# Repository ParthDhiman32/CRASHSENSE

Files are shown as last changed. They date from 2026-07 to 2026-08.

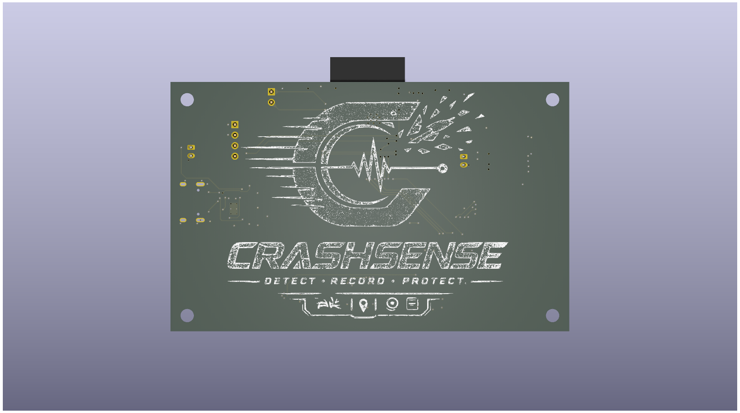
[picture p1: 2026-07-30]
RENDERS/Crashsense PCB Render-2.png

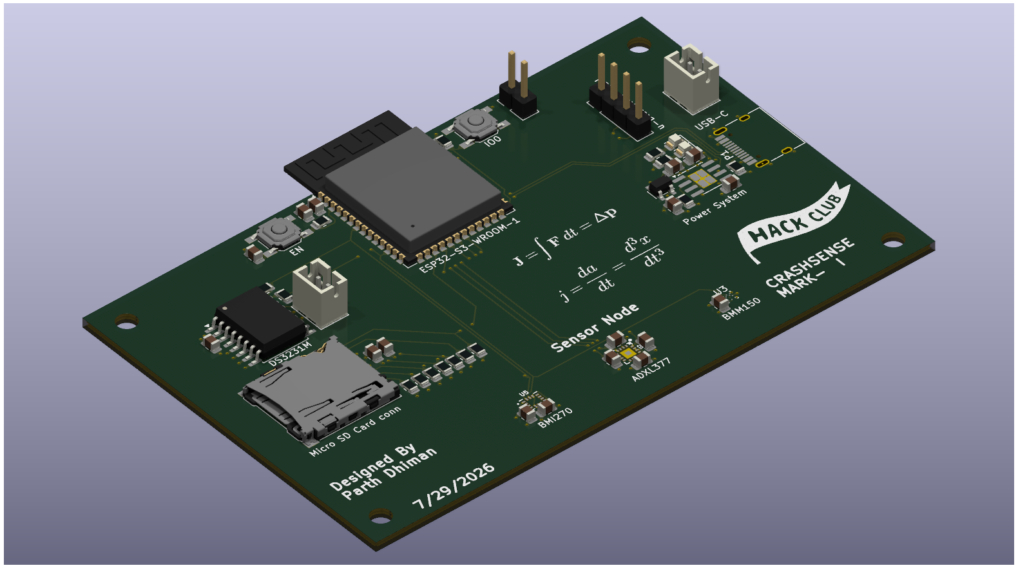
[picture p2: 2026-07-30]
RENDERS/Crashsense PCB Render-3.png

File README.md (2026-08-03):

# CRASHSENSE
Crashsense is a high level embedded sytems project which senses crashes in vehicles like cars trucks and also drones and records crital data of that crash and gives enough data for the crash to be reoncstructed 

# Why did i create this 
i created Crashesense as this is a successor to my older project Dropsense what was dropsense it was simply a embedded system device a PCB inside a hard shell cover which you could drop from any height and it would tell you exactly what height was it droppsed from and also the G-Force with which it impacted the ground

Now this idea grew from a silly project of dropping and analyzing to something bigger i decided to add the best of the best sensors and analyze the data given by then 

Basically Crashsense by it's name you can figure out it is related to something which crashes what crashes?
A lot of things Cars, motorbikes, trucks, drones, ships, and many more vehicles 
Now imagine you could take out something useful from something as negative as a crash from am engineering presepective if Crashsense is intalled in a vehicle from the start if it ever crashes it would give us a lot of DATA....DATA is the most useful thing in engineering which not only tells us how our system behaved but also can be analyzed to fugure out how to make the system behave better and be operate with more accuracy and precision 

Crashsense extracts critical data from a crash like retardation, impact velocity, angle of impact (forward, rear, side, heads on collision) which may be used by engineers to find out how the car crashed and the data may also be analyzed b forensic investigators to collect better evidence. not only all this but if you are making your own custom drone you can install crashsense on it and find out at what exact angle it falls down and how does it fall down and it'll help to pinpoint the point of faliure of the entire system

# HARDWARE & PCB SPECS 

## MICROPROCESSOR
This PCB runs on **ESP32-S3-WROOM-1** operating at speeds of 240Mhz for high frequency data sampling and sensor fusion 

## SENSORS
The main sensors used in this project are 
1. **BMI270** - 6 Axis Inertial Measurement Unit for reading  standard acceleration
2. **ADXL377** - 3 Axis Accelerometer extremely precise readings with massive reading range +-200G
3. **u-blox NEO-M8N** - Additional GPS tracting for pinpointing the location of crash 
4. **DS3231M - precise** timekeeping and timestamping the logged data

## Storage system 
**Push-Push Micro SD-Card Slot** this locks the card firmly inside it's frams and ensures no hinderance with high speed SPI communication 

## Power and Battery Management 
1. **USB-C connector** much better than old micro-usb connectors 
2. **TP4056** for recharing li-ion battries connected in araller for maximum runtime without being connected to external power source
3. **ME6211 3.3V** to step down the 5V input power to stable and low noise 3V3 volts 
4. **Li-ion battries** with JST connector for secure connection 

## Control and Diagnostics #
1. Boot and reset buttons 
2. UART debuggin header (incase USB-C fails to work)

# Schematics




# PCB
Crashsense PCB Render-1
Crashsense PCB Render-2
Crashsense PCB Render-3

# 3D CAD DESIGN



Crashsense Mark-1 3D assmebly v1
Crashsense Mark-1 3D assmebly V2

# BOM
| Component | Designator(s) | Qty | LCSC Part # | Manufacturer Part # | Package | Supplier | Total Price (USD) |
|---|---|---|---|---|---|---|---|
| Esp32 S3 | U1 | 1 | C701341 | ESP32-WROOM-32E-N4 | Module | LCSC | $2.50 |
| LowG IMU/GYRO | U2 | 1 | C2828751 | BMI270 | LGA-14 | LCSC | $2.80 |
| High G accelerometer | U3 | 1 | C138128 | ADXL377BCCZ | LFCSP-16 | LCSC | $6.50 |
| Precise RTC | U4 | 1 | C83023 | DS3231MZ+ | SOIC-8 | LCSC | $3.50 |
| 3v3 LDO Regulartor | U5 | 1 | C6186 | AMS1117-3.3 | SOT-223 | LCSC | $0.05 |
| MicroSD Card slot | J1 | 1 | C114227 | MICRO SPI Push-Push | SMD | LCSC | $0.40 |
| GPS Module Header | J2 | 1 | C124375 | Header 1x05 Pin | 2.54mm Pitch | LCSC | $0.05 |
| Power connector | J3 | 1 | C136657 | XT30PW-M | Right_Angle_SMD | LCSC | $0.50 |
| TVS Diode | D1 | 1 | C83307 | SMAJ5.0A | SMA(DO-214AC) | LCSC | $0.08 |
| Schhotkey diode | D2 | 1 | C8598 | SS14 | SMA(DO-214AC) | LCSC | $0.05 |
| I2C Pull up resistors | R1,R2 | 2 | C8598 | 4.7kΩ 1% | 0805 | LCSC | $0.02 |
| ADXL377 Filter Resistors | R3,R4,R5 | 3 | C25804 | 4.7kΩ 1% | 0805 | LCSC | $0.03 |
| ESP32 Boot/EN Pull-ups | R6,R7 | 2 | C17414 | 10kΩ 1% | 0805 | LCSC | $0.02 |
| ADXL377 Filter Capacitors | C1,C2,C3 | 3 | C15849 | 10nF 50V | 0805 | LCSC | $0.06 |
| Bulk Input capacitors | C4,C5 | 2 | C15850 | 10uF 25V | 0805 | LCSC | $0.10 |
| Decoupling Capacitors | C6,C7,C8,C9 | 4 | C14663 | 100nF 50V | 0805 | LCSC | $0.08 |
| RTC Backup Battery Holder | BT1 | 1 | C70377 | CR1220 Holder | SMD | LCSC | $0.15 |
| **Electronics** | Components BOM (LCSC/DigiKey) | 1 Board | $16.89 | $16.89 | MCU, IMUs, RTC, passives, headers |
| **PCB Fabrication** | 2-Layer FR4 PCB (JLCPCB) | 1 Board (of 5) | $2.40 | $2.40 | ~$12.00 total for minimum 5-pc order + economy shipping |
| **Enclosure** | 3D Printed PETG / ABS Filament | ~50g | $1.00 | $1.00 | Based on standard $20/kg spool (tough PETG/ABS) |

### Total Cost Summary

* **Single Unit Build Cost:** **~$20.29 USD**
* **First 5-Board Prototype Run:** **~$98.45 USD** *(1x $20/kg Filament Spool + 5x Component Sets @ $16.89 + 5x PCBs @ $12.00)*

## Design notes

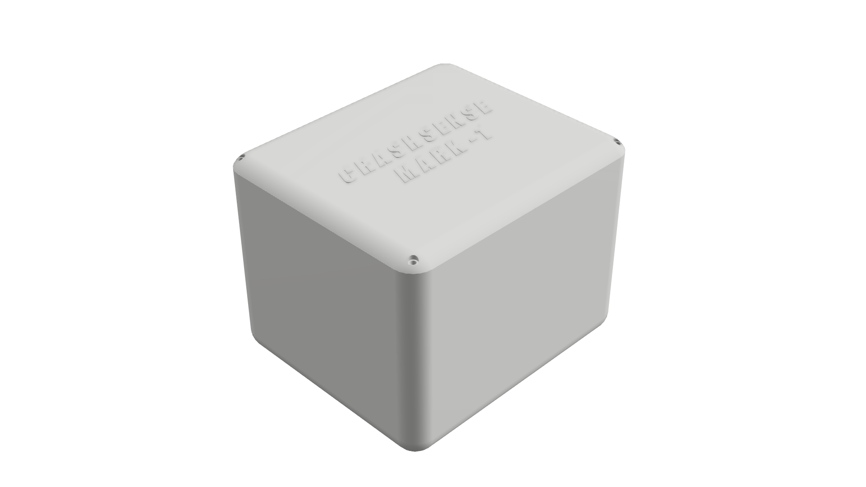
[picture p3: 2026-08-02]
RENDERS/Crashsense Mark-1 3D assmebly v1.png

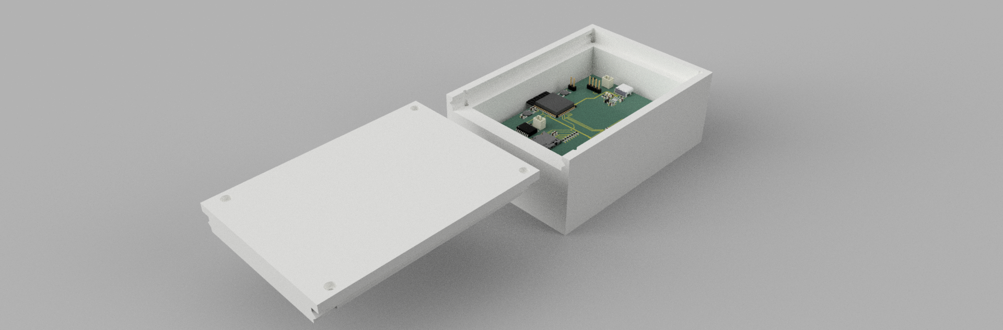
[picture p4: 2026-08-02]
RENDERS/Crashsense Mark-1 3D assmebly V2.png

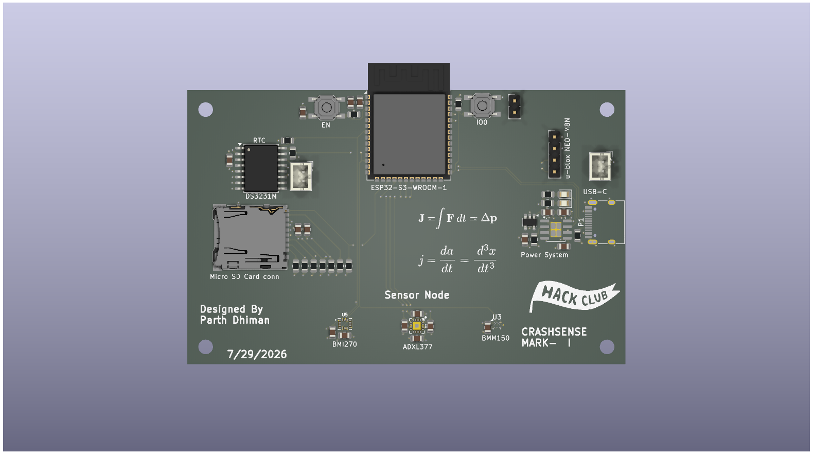
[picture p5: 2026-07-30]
RENDERS/Crashsense PCB Render-1.png

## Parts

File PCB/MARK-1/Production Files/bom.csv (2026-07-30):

Designator | Footprint | Quantity | Value | LCSC Part #
 | f59ac847-f748-4106-ba1d-d1278d51b1ea | 1
C1, C15, C2, C4, C5 | 0805 | 5 | 10uF
C10, C8, C9 | 0805 | 3 | 10nF
C11, C12, C13, C14, C16, C6, C7 | 0805 | 7 | 100nF
C17, C3 | 0805 | 2 | 1uF
D1 | 0805 | 1 | RLED
D2 | 0805 | 1 | GLED
J2 | microSD_HC_Hirose_DM3AT-SF-PEJM5 | 1 | Micro_SD_Card_Det1
J3 | JST_PH_B2B-PH-K_1x02_P2.00mm_Vertical | 1 | BATTERY_CONNECTOR
J4 | PinHeader_1x02_P2.54mm_Vertical | 1 | Debug_pins
J5 | JST_PH_B2B-PH-K_1x02_P2.00mm_Vertical | 1 | Coincell_BAT
P1 | USB_C_Receptacle_HRO_TYPE-C-31-M-12 | 1 | USB_C_Plug_USB2.0
R1 | 0805 | 1 | 5.1KR
R10, R11, R14, R15, R5, R6, R7, R8, R9 | 0805 | 9 | 10KR
R12, R13 | 0805 | 2 | 4.7kR
R2 | 0805 | 1 | 1.2KR
R3, R4 | 0805 | 2 | 1kR
RTC | SOIC-16W_7.5x10.3mm_P1.27mm | 1 | DS3231M
SW1, SW2 | SW_SPST_SKQG_WithStem | 2 | SW_Push
U-BLOX NEO-M8N | PinHeader_1x04_P2.54mm_Vertical | 1 | u-blox NEO-M8N
U1 | ESP32-S3-WROOM-1 | 1 | ESP32-S3-WROOM-1
U2 | LFCSP-16-3X3 | 1 | ADXL377
U3 | WLCSP-12_1.56x1.56mm_P0.4mm | 1 | BMM150
U5 | XDCR_BMI270 | 1 | BMI270
U6 | SOIC-8-1EP_3.9x4.9mm_P1.27mm_EP2.41x3.3mm_ThermalVias | 1 | TP4056-42-ESOP8
U7 | SOT-23-5 | 1 | ME6211C10M5

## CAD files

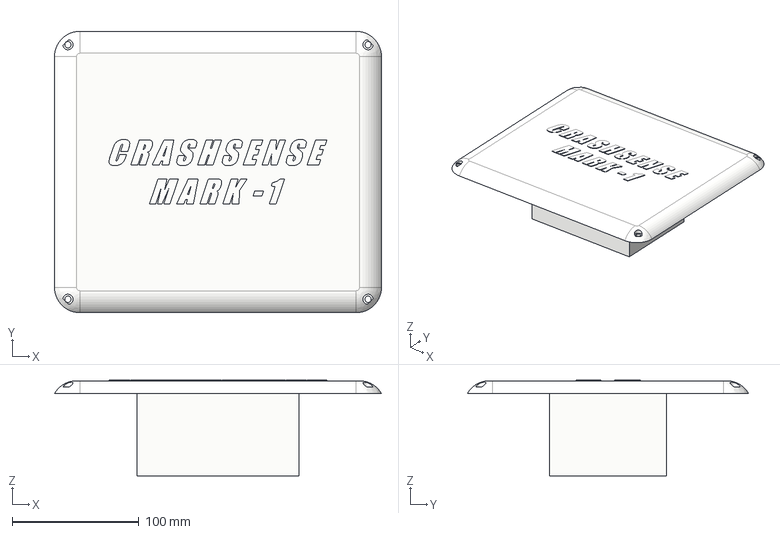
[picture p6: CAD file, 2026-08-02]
CAD/3D Printables/.STEP/Crahsense outter shel part-2 v4.step
258.0 x 222.1 x 75.5 mm

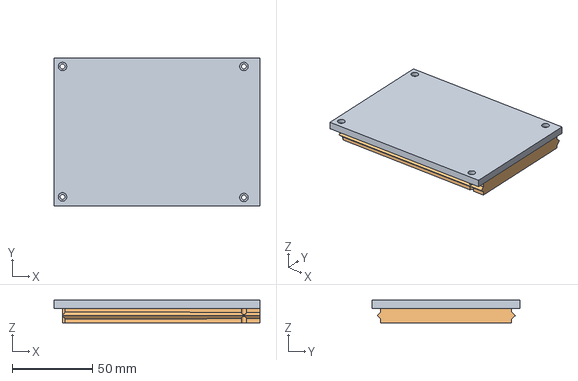
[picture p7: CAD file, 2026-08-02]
CAD/3D Printables/.STEP/Crashsense Mark-1 LID v10.step
128.0 x 92.0 x 14.0 mm

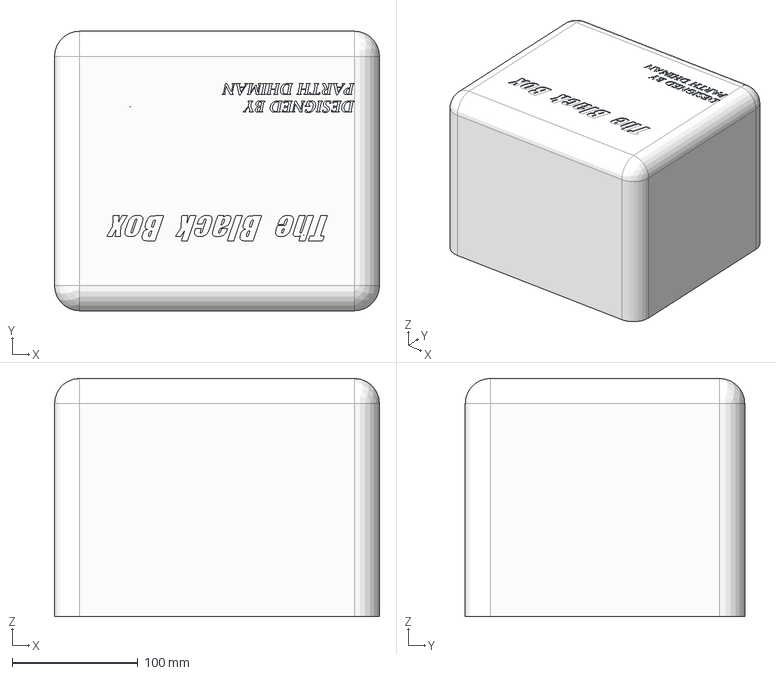
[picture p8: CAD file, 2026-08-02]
CAD/3D Printables/.STEP/Crashsense outter shell part -1 v5.step
258.0 x 222.1 x 189.0 mm

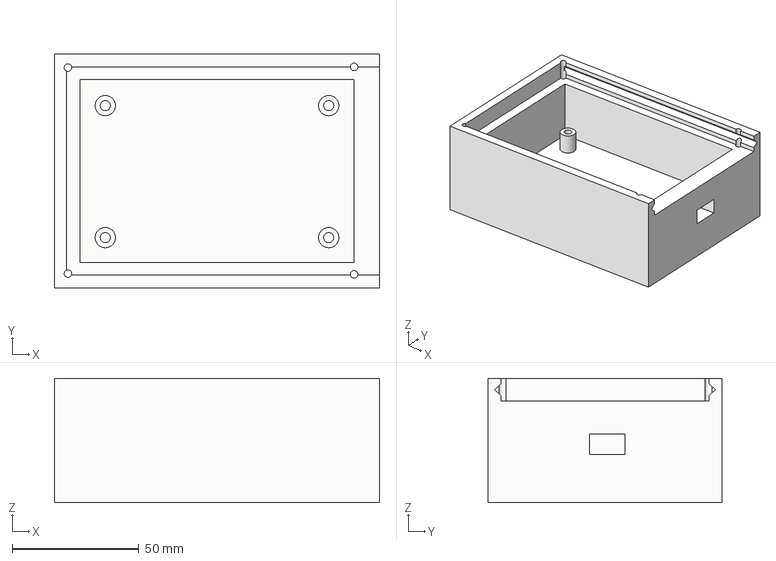
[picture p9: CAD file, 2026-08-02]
CAD/3D Printables/.STEP/Crashsense Mark-1 Enclosure Part-1 v24.step
128.0 x 92.0 x 49.0 mm

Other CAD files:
CAD/3D Printables/.F3D/Crahsense outter shel part-2 v4.f3d
CAD/3D Printables/.F3D/Crashsense Mark-1 Enclosure Part-1 v24.f3d
CAD/3D Printables/.F3D/Crashsense Mark-1 LID v10.f3d
CAD/3D Printables/.F3D/Crashsense outter shell part -1 v5.f3d

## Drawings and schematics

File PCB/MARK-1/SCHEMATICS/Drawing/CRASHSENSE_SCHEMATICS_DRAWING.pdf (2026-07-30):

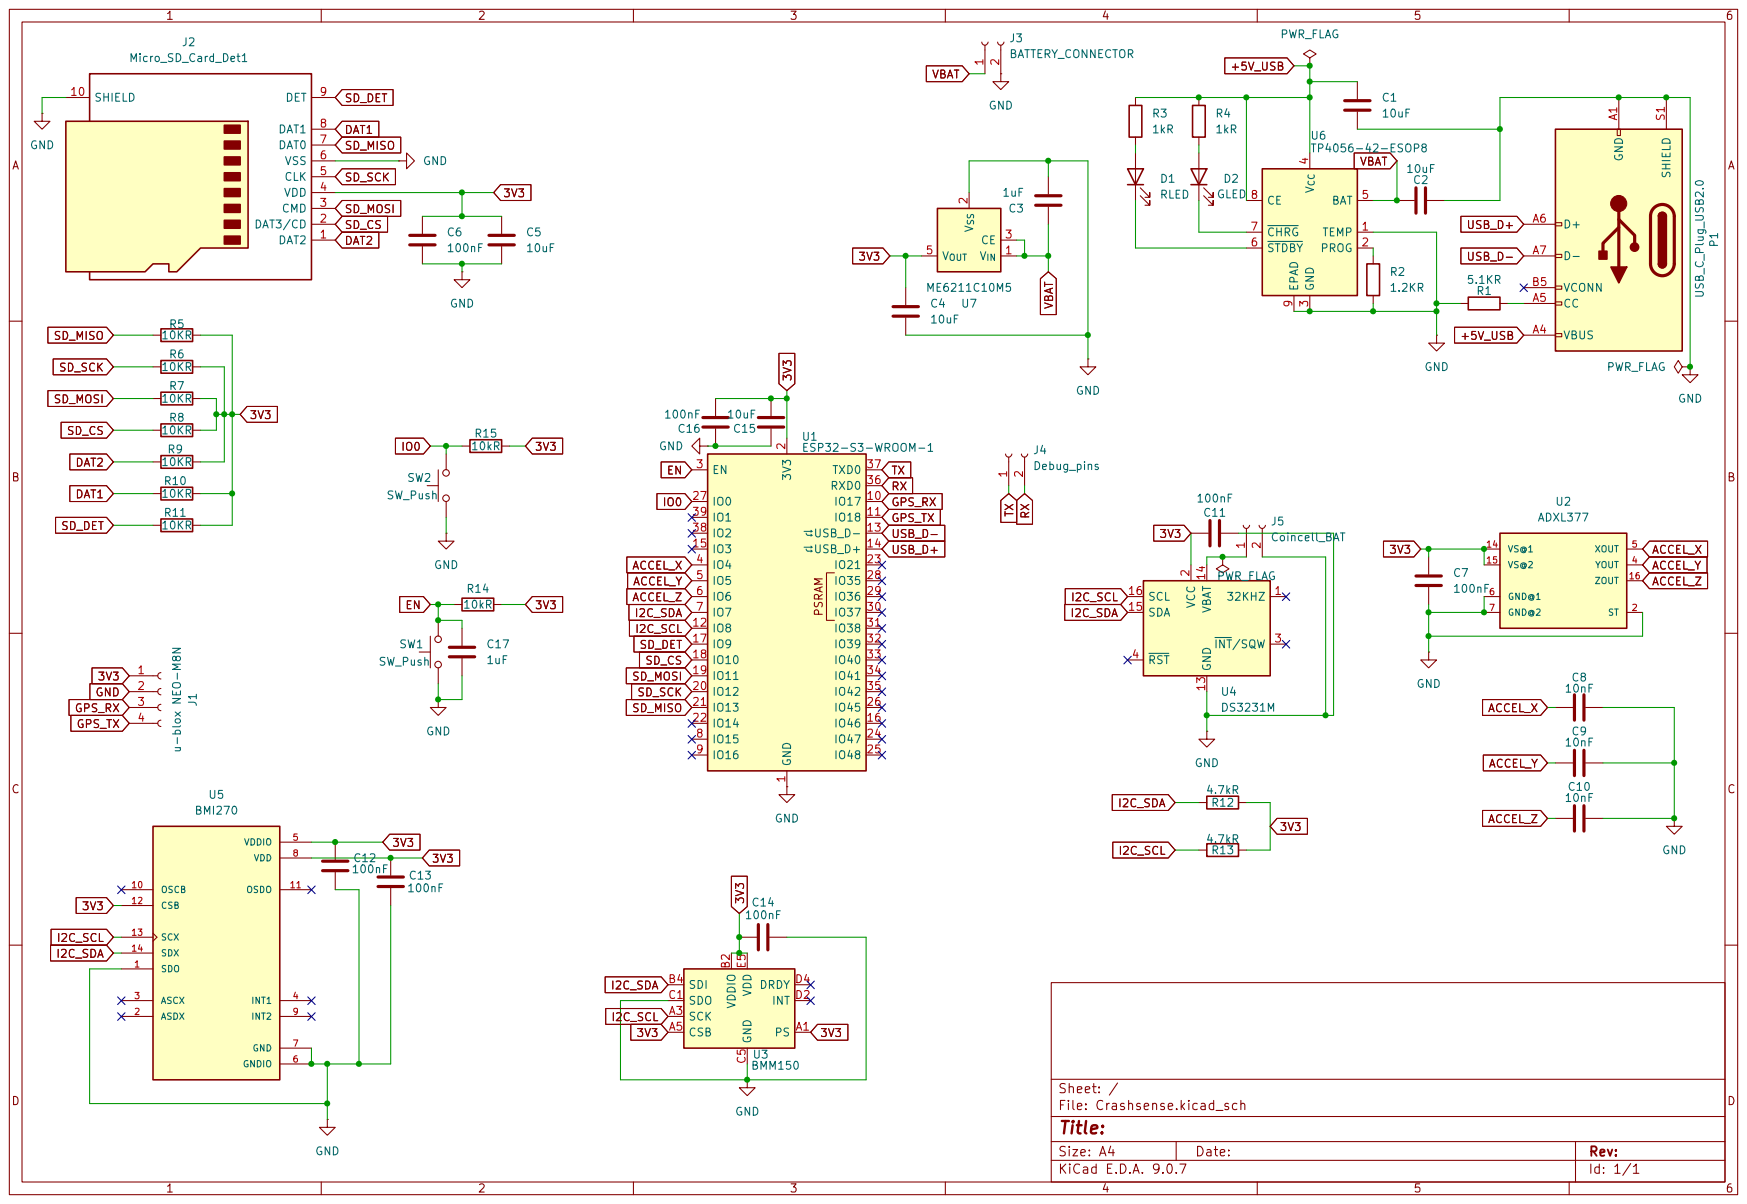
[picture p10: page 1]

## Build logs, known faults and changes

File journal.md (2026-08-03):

---
Title: "Crashsense"
Author: "Parth Dhiman"
Description: "Crashsense is a smart crash analysis system which recods data of a crash and has SOS features"
Created_at: "2026-7-22"
---

# July 22nd: Setting up and researching!

So today is the day i started my work for horizons-equinox in this session all what i did was to simply set up hackatime for VS code and also learn how to journal and use github it was a bit hard to set up because horizons equinox is mainly for software projects but to also log hardware projects i also needed to learn how to sync hackatime and lapse so i can track both my coding time and the time i will be speding on my CAD and PCBs 
So what project am i making is something you might be wondering i am start to work on crashsense actually this is a continuation of my last project Dropsense dropsense was a great learning project basically you could drop it from a certain height and it would log all the data of the drop but now i want to upgrade my project i am going to another level with this project i am willing to make a device which could be mounted in a car ans which could record all sorts of inertial measurements of the car now you would ask me does that not already exist which i would give am answer to as yes! it already does exist but what the point is for making this project is that i am making this project as a learning project and i will also try to include as any features in it as i can so i may also be able to patient it in the future! and yes i will now start to research for this project deciding which are the best sensors to use in this and ones with the maximum data collection rate!

OKay so this is after i researched for the project and i have a lot to say first of all let me list all the parts i will be using in this project 
1. ESP32-S3-WROOM-1
2. ADXL377
3. QMC5883L
4. BMI270
5. micro sd
6. DS3231 
7. u-blox NEO-M8N
8. USB C
9. TP4056
10. ME6211 3v3
so let me talk about each and evey part one by one 

no-1 we have esp32 s3 wroom-1 module which is the microcontroller i will be using for this project this is the brain of the entire system i am planning to use this because of it's very high operational frequency of upto 240Mhz which is enough for my project which needed data sampaling at a very fast rate and also because of it's abundant GPIO pins which will allow me to connect all of the above listed compoennts 
next up 

no-2 ADX377 this is the best accelerometer i could find because it records acceleration upto +- 200g in all 3 axes with maximum accuracy and i don't think a better accelerometer than this for my budget exists i will be using as car crashes have an massive magnitudes of retardation 100-200g and as the range of this sensor falls withing the range of a typicall car crash it will most probably be able to record most of the critical data 

no-3 QMC5883L is a 3 axis digital compass which measure's the earth's magnetic fields accurately and gives accurate compass directions this will help me to figure out what direction the vehicle is heading to The best part i can combine this with the accelerometer and tell if a collision happens which direction did the collision hapenned from read end or frontend or side impact very accurately 

no-4 BMI270 now this is a very powerful gyroscope it also does feature a accelerometer but we do not require that as we are already using ADX377 which is much much better than the accelerometer featured by this 
Now if i combine the acclerometer the compass and this gyroscope sensor together i now have the ability to capture a new variety of crash which is if the car rolls over or falls down a hill now i can detect rotation yaw and pitch by sensor fusion 

no-5 i will be using a simple sd card module to log the data now you may be asking why use a sd card they are not that fast to log tens of thousands of bits of data at a very low frequency now we can fix this issue by simply logging a chunk of data in the 512KB of Sram the esp32 s3 wroom-1 offers and then load that into the sd card at once ad repeate this process and it makes logging the data much more relaible 

mo-6 DS3231 is a RTC module which i will use to add timestamps to each of my readings in formats of dd/mm/yy for header reading and then readings for the actual logged data will be logged in intervals f miliseconds as per the esp32 s3 wroom-1' clock

no-7 u-blox NEO-M8N this is a pretty good enough GPS for crashsense as i also want to record the velocity of the crash and also for future upgrades i want to give the exact co-ordinates where the crash most probably took place 

no-8,9,10 TP4056 now here comes the power system which i would like to cover all together so first up comes the usb-c which i will using to power program and test the entire pcb firstly the 5V power enters through the USB and then i use the TP4056 module to charge the onboard li-ion battery which will power the entire system for now i will add a more complex power system in the pcb which enable the pcb to run directly off of the 11.8 to ~14 V from the lead acid car battery and yes i will also add supercapacitors later incase the battery wires snap during a crash 



**Total time spent: ~2h** for the lapse + journal if talking only about the journal i spent a exact time of 1 hour and 7 mins on it because i mostly did research and wrote my views here today 

# July 23rd: Deeper research and Pcb schematic development!

So guys today's decided goal is to complete adding all the parts i need for my project in the schematic and then 
hopefully start the routing 

So i decided to make a change in the magnotemeter i'll be using instead of using a QMC5883L 3 axis magnometer 
i will instead use BMM150 which is also a 3 axis magnetometer but this one is made by bosch and hence 
is much more relaible

so first of all what i did was to place all the parts in the KiCAD schematics editor 
I got most of the parts in the default library but i needed to add a few special sensors like ADXL377 and the 
BMI270 3 axis accelerometer and gyroscope from bosch 

now first of all i started to wire up the power system consistong of a USB C connector TP4056 for charging the battery and also a ME6211 to step down the voltage from 5V from the USB C to 3V3 volts on which the entire system will operate on if any sensor requires exact 5V signal i will either use a I2C signal logic level converter because f i directly feed the sensor 5V it will be output 3V3 signals to my ESP32 S3 and cook it 

so i worked on the power system i wired up a USB C connector to my TP4056 battery power managemnent IC and use it to charge my 
li-ion battries and also give the 3V3 volt regulator aka the ME6211 which is being fed the 5V from the TP4056 
for it to be convertyed into stable 3V3 volts also i added 10uF capacitors at the input and output of each of the 
regualtors to store power and to stabelize voltage fluctuations which may take place 


after this i wired up the sd card module and added net labels for easily connecting them to my ESP32 S3 WROOM-1 module 
also i added one 10uF capacitor at the inputs of the SD card module to stabelize the voltage and a 100nF capacitor to 
filter out the any noise in the power signals which may interfere with the SD card module 


## overall PCb schematic as of today 


**Total time spent: ~2.5h** (including lapse and journalling)

# July 24th: PCb schematics continued!

sooo guys my goal for tonight is to route 3 more sensors properly like not properly perfectly flawlessly so that 
i would not worry about my connections being wrong 

I started by wiring up the very easy u-blox-NEO-M8N GPS which uses only vcc gnd and I2C pins which make 
the connections very easy 

then i connected the ADX377 to my esp32 s3 i added a 100nF decoupling capacitor and also added 10nF capacotors at X Y and Z 
output pins to set the data sampaling speed to 200Hz

after that i made a master I2C rail over which i connected all the I2C devices mainly the DS3231M RTC 

and lastly i connected the BMI270 IMU which i'll be using for reading the gyroscopic values for all 3 axes 


\



**Total time spent: ~1.3h** (including lapse and journalling)

# July 25th: PCB schematics finished!
So guys my goal for today is to finish the pcb and then organize the schematics and optimize it for redability 
to make it look proffesional afterall

so firstly i wired up the last piece the BMM150 the 3 axis compass which will be used for telling which direction the vehicle 
is headed to and from where did the crash occur 

what i learnt that i always have to connect a 100nF resistor with every IC because it stabelizes the power input 
and also helps to reduce impact of high frequency signals on the IC 

as for the ESP32 S3 wroom-1 module which i mostly use in my projects i need to connect 2 resistors to it 
firstly the bulk charge holder 10uF capacitor and then the noise reducing capacitor aka the 100nF capacitor 
the combination of the two helps with fluctuating power and signal noise 

alright now after adding these changes i also added the RC delay circuit for the EN pin with a 10kR resistor 
and a 1uF resistor and a reset circuit for the IO0 pin to decide wether to put the ESP32 in running or uploading module

then i also added 2 pins the RX and TX as pin headers on the PCB so that i can still upload the code to my esp32 
is my USB fails to program or detect the ESP32 which has hapenned to me in the past so i mostly use a FTDI 
module connected to the ESP32's RX and TX pins to flash it 

now i have another bigger obstacle in my way i need to organize everything all the components in the schematic

alright now i organised everything inside the schematic
The power delivery system is at the top right 
The esp32 s3 wroom-1 with all it's connection flags is placed in the center the accelerometer and the gyroscope sensor to it's right
The RTC and the RC delay and Reset circuits are on the leftthe sd card module on the top left 

Now i ran the most critical part the ERC 
first it showed 5 errors and 3 warnings 
the 5 errors pominted to 2 unconnected pins which i forgot to place a no connection mark on and 
the other 3 were pointing at the +5V_BAT the 3V3 and the GND i just needed to add 3 PWR_FLAGS to them to fix it
Then i ignored the warnings because they were pointing at some silly stuff and i saw ZERO!!!!! DRC errors

now i added footprint for each and every component used from a single resistor to the BMI270 all have the footprints assigned
now i converted everything to a pcb and i already know it is going to be a hell of a routing session 

Here are the screenshots of today's work 






Which i decide to save for tomorrow 

**Total time spent: ~2.2h** (including lapse and journalling)

# July 26th: PCB component placement started!

Alright guys so yesterday i had completed the pcb schematics and today i started to arrange all the components on the pcb 

So the strategy i use to arrange the components perfectly is that i divide the entire PCB into sub systems like the power system the micro controller system and each and every sensor is firstly seperated 

I would call this a pretty good feature of Kicad that it lets us select the components on the pcb editor just by selscting them in the Schematics editor this does not exist in easy EDA 

Anyways after diving each and ever subsystem i start to place the passive SMD components like resistors capacitors connectors and inductors close the the main chip that im working on for eg the most crutial part is the power system so to ensure minimum EMI the compoenets need to be as closely packed as possible like the smd components need to be hugging the power IC like actually so close that it literally cannot be any closer this helps to greatly reduce EMI and keeps the signals stable and noise free because long power traces can act as a antenna and disturb other components such as the most sensetive magnetometer 

after the power system i worked on the ESP32 as i said earlier the decoupling capacotors near the ESP32 S3 should should be placed as close it as possible

Then moving on to the SD card module if you look closely you'll be able to see an array or resistors which are connecting to the SD card module and 3V3 rail That is an array of Pull up resistors pulling up each and evey single pin on the SD card module because without it the micro SD card module becaomes highly unstable and may be affected by tiny bt of electro magnetic interference and read data wrongly and may even corrupt the SD card module 

Then we move to the sensors in this PCB the ADXL377 and the BMI270 are placed close to each other because they can be BUT! you may notics that the BMI270 is kept far away from each of these sensors and even the power rails this is done on purpose because the BMI150 is a very accurate but ultra sensetive magnetemeter and even a tiny bit of current will WILL acceft it's reading so that is the reason why this HAS to be kept away from evey other component 

and then in the end what I needed to do is to make a Edge.Cuts layer of size aprox 70 by 50 mm inside which i had to keep att the components now this is pure hit and trial you need to logically reason the placement of every subsystem on the PCB in such a way it compliments the working of other subsystem instead of interfering with then like the ESP32 and the power system are best friends and need to be together for proper power delivery and the RTC module is above the SD card module because the array of the Pull up resistors need space for connecting with the ESP32 and so and so 

Now today's goal is complete and now i plan to route this PCB tomorrow and make minor adjusments in the layout for ease of routing 

Here is how the PCB looks today after today's work VS how it did look yesterday 
**Yesterday**

**Today**


**Total time spent: ~~2h** (including lapse and journalling)

# July 27th: PCB component Routing disaster!
sooo guys i started to route my pcb today and i went for a 4 layered PCB because i had never made it before and i guessed it would be the perfect opputunity to learn 
how to trace a 4 layered PCB 

But things didn't go as planned well they did i routed a lot of things but the thing is that i myself do not understand properly how did the connections trace like 
i cannot see each and every tract properly taht's why it seems very very confusing but yes i can say i did make progress but i am not able to recognize it properly 

anyways i do not have a lot to say today so i would like to imclude a screenshot of today's work and end it also because i haven't slept properly so i should sleep 


**Total time spent: ~1h** (including lapse and journalling)

# July 28th: PCB rerouting with peaceful mind  !
SOO GUYZZ so first of all i started by unrouting all the traces i made because they just didn't feel right and i felt like i speedran 
then and after that i reomved all the components out of the edgs.cuts layer and started to place each and every sub-system together 
and i also decided that i will need to increase the size of the pcb because a smaller form factor would only make things really hard 
to route so as the engineering industry standard if something doesn't work i just scrap and discard it and start over again 
that is exactly what i did i discarded the old component placement and then seperated each and every systed and 
adjusted every capacitor or resistor which i felt like needed to be.

after adjusting every single component the next part was that i needed to convert the PCB physically into a 4-layered PCB for that i first needed to go 
in FILE and then BOARD SETUP and then PHYSICAL STACKUP 
then i needed to change the no of layers from 2 to 4 layers and kicad automatically added in1 and in2 layer 
So the in1 layer was configured as the GND plane and the in2 layer was configured as the 3V3 plane 
as the entire board runs on 3v3 volts i only need GND and 3V3 as 2 extra layers for seperating the power system from the rest 
of the board 

Then after doing this i started to route the PCB first of all what i needed to do was to add vias to all the GND 
pads so that i could connect them directly to the GND plate 

after adding all the GND vias i realised that every via must be as close to the pad as possible so i rechecked every via i made and 
then made minor adjustments in the location of vias with respect to the GND pad 

here is the yesterday's before and today's after 

## BEFORE ##


## AFTER ##


If you cannot tell the difference let me explain so first of all the yesterday's PCB is much much smaller and cluttered than the pcb i made today 
and also the new pcb has M3 mounting screws in comparision to the old one which doesn't even have a proper visibally viable division of sub-systems  

Also the most important update that i made in this PCB is that i added a sensor array at the base of the PCB as the snsors share the same horizontal axis on the 2 dimensional plane of the PCB they will be synced and provide harmonius information which is more accurate and can be worked uptom more freely

**Total time spent: ~1.3h** (including lapse and journalling)

# July 29th: PCB final routing and makeing it look good!

Sooo guyss today's session was longer than other session because now i am going to speedrun the PCB now as the deadline is getting close 
So about what i did Today

as of yesterday i was routing the GND pads by that i mean adding VIA for GND near every GND pad and why is that so you may as??
This is because i was making a 4 layered PCB well i was going to give up and make a 2 layered PCB instead but no 
i did continue with the 4 layered one so till yesterday i had added all the GND VIAS and today i contunued by adding the
VIA for the 3V3 plane and then i soon realised i made a blunder which would cost me a lot in manufacturing the PCB 
the blunder i made was that i asses the 3v3 pads as close to the pad as possible ik that is how it is supposed to be but my mistake was that i made the pad and the VIA touch 
which seemsokay in design stage of PCb assembly but causes the manufacturing cost to shoot up because during the solder reflow stage of the PCB the 
solder runs down through the holes and more of it ends up being used and hence costing more 

now after this what i did was to rerout the power system for the power system i started by routing the TP4056 IC and then 
the ME6122 3V3 voltage regulator LDO  and then i used a lot of brain in maximizing the efficiency of the power system by reducing the trace length and using VIA 
efficiently 

After the voltage regulation body i.e. power system was done i moved over to connecting the power pins of the ESP32 
first the power pins and then the EN and IO0 switches were wired up something different that i did this time that i do not usually do while routing pcbs is that 
when i make traces most of the times i just folow what the software guides me as the best track or VIA position but i learnt that if i hold down the CTRL key
and then move my mouse then the track used to move very smoothly as if now i have entire soul of the track in the pal of my hand 
now i made a lot of very beautiful traces that i am really proud of 

Then i worked my way over to the I2C rails i had a very good idea this time that i will first make a common rail 
for every I2C device which was a really good idea because it worked properly and it also looked much better then connecting the I2C 
traces any other way after my inner perfectionist perfected the tracks i was satsfied and then 

and then was left another sesnr or two why? because they had different pins because they use SPi protocol instead of 
I2C protocol like the micro SD Card module and then ADXL377 

and after this i was done with allll the connections 

Then....i ran the DRC and it showed me 8 errors and 15 warnings from those 8 errors 5 errors were that i had left unconnected items in the power system 
but in reality the thing is that i did wire them up but suddenly i pressed shift + W and idk when i press it my computer crashes everytime 
and i have to start Kicad again but it loads it from the place of last save 

Anyways after fixing those 5 errors i went to 3 more errors which were telling me that the edge.cuts layer wasn'ta
aligned properly with the 3V3 and the GND plate then i shifted the border a bit and fixed the PCB now i only had warnings telling me to not clip the silkscreen but bro now i can ofc 
have silkscreen over or under the electronics it's not like it will interfere with the PCB 

After doing any and every change i could have done to beautify the PCb like i even added teardrops in the PCb and after that the 
VIA suddenly looked much much better 

now came the fun part i imported a few SVj files to add on the PCB 
mo-1 i wrote my name and project name "Crashsense mark-1" and also the date i made it and then i added hack club' flag 
to the front of the PCB and an AI generated very cool SVJ file which was a graphical symbol of crashsense on the entire back of the PCB 
and lastly i added the core of the systed i added 2 hysics equations on whose principal does crashsense work and then put them near the heart of the ESP32

Okay so i think these are enough for today now i should sleep properly 

here are the PICs of today's work






**Total time spent: ~3.5h** (including lapse and journalling)

# July 30th: PCB Finalization!
SOOO GUYZZ today what i did was that firstly i rendered the pcb i took one render from the top view of the PCB
another from the back side of the PCB which has the crashsense logo and 3rd render was a sideways slanting render
which looked absoultely fire 

after this i explorted the production files for the PCB like the GERBER the BOM and the PLACE file for the PCB 
using the custon added fabrication toolkit 

then i also exported the schematics of the pcb as a PDF file inside the PCB folder and yeah after this i ploshed 
the readme added different sections and many many images of my work

andd after all of updating the readme writing new things and highlighting all the stuff about the PCb I did till now i started to work on the 3D Enclosure for the PCB and that's when i realised i don't have a very clear idea of how the actual 3d design should look but for the begining i will make a very simple enclosure and then work on it and transform it into an even better design day by day hour by hour minute by minute 

I have the theoretical design in my head that is that this project will have a inner hard PETG shell inside which the pcb will be present and a soft outter TPU shell which will deform and squish during the impacts and let the inner hard shell protect the PCB 
actually during an impact what i really want that survives is not the PCb but rather the Mirco SD card module because it will be storing all of the critical data and furthermore i plan to make the areas where the SD card resides the toughest area 

Here is the design made till now


**Total time spent: ~2h** (including lapse and journalling)

# July 31st and 1st august: 3D Design progress!
Alright so today was a pretty productive day what i did was work on the 3D CAD enclosure for my PCB which 
i had started yesterday on yesterday it was just a single part box 

today i made the following changes 
1. Made a cutout for the USB Type C connector in the enclosure 
2. Added M3 heat inserts in the small pillars i made for mounting the PCB regidly 
3. Added M3 screws to mount the PCB inside the enclosure 
4. Added a lip on the outter perimeter of the TOP of the enclosure for sturdy connection with the LID 
5. started working on the lid and made a coresponding outter lip on it's perimiter for proper locking of the lid
6. Added M3 screws connecting the lid and the enclosure together 
7. added a interlocking lip for sturdy connection of the lid with the body 
8. created outter hexagonal pattern housing which will sqush and break on impact protecting the inner PCB 






**Total time spent: ~5-6h** (including lapse and journalling)

# 2nd August: Outter shell designing and assembly video!
SOOO GUYZZ in today's session i worked on the outter hexagonal design for the PCB this outter shell is intended to crush and break on impact to protect the inner 
Main PCB housing of Crashsense 

The utteroutter housing holds the inner housing and there is a 5mm wall between the inner and outter housing before the haxagonal pattern starts and 
also a 5mm thick outter wall on the perimeter of the outter shell and the inside is filled with hexagons and when it will be hit the outter wall will distribute the impact to a 
specific wall and the entire wal will transfer the force toi a array of hexagons instead of a specifi hexagon and will make the
all the hexagons compress on impact and once the force ends the hexagons will restore to their initial position if the impact was not strong 
enough to break them 

after completing this design i took a few renders of the entire design 

after thr renders i made a exploded view of the entire assembly and also animated each part showing how the assembly works and it should exisit this is the yt video link
https://youtu.be/XTUrnmSj-00
after making the animation and uploading it on youtube 
I started to export all the CAD files in the respective folders and make each and everything organised 

and now the entire CAD and PCB part of this project stands complete i will now proceed to ship this project 

Crashsense Mark-1 3D assmebly v1
Crashsense Mark-1 3D assmebly V2

**Total time spent: ~2h** (including lapse and journalling)

# 2nd and 3rd August Starting and finishing up code!

first of all i replaced the traditional loop() approach because reading sensors and wiring data to the SD card could easily cause delays and miss data 

I designed a dual core memory firmware architecture using FreeRTOS 

1. Core 0 Reads data from the ADXL377, BMI270, and Neo-M8N every 5 ms (200Hz) and stores it in a ring buffer containing 2 seconds of data 

2. Core1 Waits in the background untill a crash is detected and then saves the buffered data along with the 5 seconds of post Crash data to the SD card.

Developed crash detection logic that continuoosuly checks the acceleration and if the acceleration stays above a threeshold for a short period of time the system triggeres data logging 

the firmware now does not interfere with the SD card ogging and reading the Sensor data 

**Total time spent: ~2h** (including lapse and journalling)

# 3rd August Finalizing the BOM!
SOOO GUYS in this video i exported the ropugh BOM from kicad and then formatted a few more things and now i have a rough cost of the project which comes out to be around 16$ and this does not include the fabrication cost because that varies manufacturer by manufacturer and rough cost would be around 10$ 
yk what let me just include it 
 
anyways as this project is already shipped i do not have much to do but wrap up this project

**Total time spent: ~1h** (including lapse and journalling)

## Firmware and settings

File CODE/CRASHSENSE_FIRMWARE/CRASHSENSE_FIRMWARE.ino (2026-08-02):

/** CRASHSENSE MARK-1 FIRMWARE **/
#include <Wire.h>
#include <SparkFun_BMI270_Arduino_Library.h>
#include <RTClib.h>
#include <TinyGPS++.h>
#include <HardwareSerial.h>
#include <SPI.h>
#include <SD.h>

// --- PIN DEFINITIONS & CONSTANTS ---
#define RXD2 16
#define TXD2 17 
#define GPS_BAUD 9600 

const int PIN_X = 32; 
const int PIN_Y = 33;
const int PIN_Z = 34;
const int SD_CS_PIN = 5; // Standard ESP32 VSPI CS pin

const float V_REF = 3.3;            
const float ADC_MAX = 4095.0;       
const float ZERO_G_VOLTS = 1.65;    
const float SENSITIVITY  = 0.0065;  

// --- GLOBAL OBJECTS ---
RTC_DS3231 rtc;
TinyGPSPlus gps;
HardwareSerial gpsSerial(2); 
BMI270 imu;

// --- DATA STRUCTURES & RTOS GLOBALS ---
struct SensorFrame {
  uint32_t timestamp_us;
  float ax, ay, az;
  float gx, gy, gz;
  float lat, lng;
  uint8_t hour, minute, second;
};

const int BUFFER_SIZE = 400;
SensorFrame ringBuffer[BUFFER_SIZE];
volatile int headIndex = 0;

QueueHandle_t crashQueue;
TaskHandle_t SensorTaskHandle;
TaskHandle_t SDTaskHandle;

// --- CORE 0: HIGH SPEED SENSOR TASK ---
void core0_SensorTask(void *pvParameters) {
  TickType_t xLastWakeTime = xTaskGetTickCount();
  const TickType_t xFrequency = pdMS_TO_TICKS(5); // 200 Hz

  int impactCounter = 0;
  bool crashStatusLocked = false;

  for(;;) {
    // 1. Read Analog Accelerometer
    float gX = (((analogRead(PIN_X) / ADC_MAX) * V_REF) - ZERO_G_VOLTS) / SENSITIVITY;
    float gY = (((analogRead(PIN_Y) / ADC_MAX) * V_REF) - ZERO_G_VOLTS) / SENSITIVITY;
    float gZ = (((analogRead(PIN_Z) / ADC_MAX) * V_REF) - ZERO_G_VOLTS) / SENSITIVITY;

    // 2. Read Digital IMU
    imu.getSensorData();

    // 3. Update GPS data in background (non-blocking)
    while (gpsSerial.available() > 0) {
      gps.encode(gpsSerial.read());
    }

    // 4. Get Time
    DateTime now = rtc.now();

    // 5. Write to Ring Buffer
    ringBuffer[headIndex].timestamp_us = micros();
    ringBuffer[headIndex].ax = gX;
    ringBuffer[headIndex].ay = gY;
    ringBuffer[headIndex].az = gZ;
    ringBuffer[headIndex].gx = imu.data.gyroX;
    ringBuffer[headIndex].gy = imu.data.gyroY;
    ringBuffer[headIndex].gz = imu.data.gyroZ;
    
    if (gps.location.isValid()) {
      ringBuffer[headIndex].lat = gps.location.lat();
      ringBuffer[headIndex].lng = gps.location.lng();
    }
    
    ringBuffer[headIndex].hour = now.hour();
    ringBuffer[headIndex].minute = now.minute();
    ringBuffer[headIndex].second = now.second();

    // 6. Crash Detection Logic
    float aTotal = sqrt((gX*gX) + (gY*gY) + (gZ*gZ));
    
    if(aTotal > 5.0 && !crashStatusLocked) {
      impactCounter++;
      if(impactCounter >= 4) {
        crashStatusLocked = true;
        int freezeIndex = headIndex;
        xQueueSend(crashQueue, &freezeIndex, portMAX_DELAY);
      }
    } else {
      impactCounter = 0;
    }
     
    // 7. Advance Buffer and Delay
    headIndex = (headIndex + 1) % BUFFER_SIZE;
    vTaskDelayUntil(&xLastWakeTime, xFrequency);
  }
}

// --- CORE 1: ASYNCHRONOUS SD CARD TASK ---
void core1_SDTask(void *pvParameters) {
  int freezeIndex = 0;

  for(;;) {
    if (xQueueReceive(crashQueue, &freezeIndex, portMAX_DELAY) == pdPASS) {
      File dataFile = SD.open("/crash_log.csv", FILE_APPEND);
      if (!dataFile) {
        vTaskDelete(NULL); // SD failure, kill task
      }

      // Dump pre-crash history
      int readIndex = (freezeIndex + 1) % BUFFER_SIZE;
      for(int i = 0; i < BUFFER_SIZE; i++) {
        dataFile.print(ringBuffer[readIndex].timestamp_us); dataFile.print(",");
        dataFile.print(ringBuffer[readIndex].ax, 2); dataFile.print(",");
        dataFile.print(ringBuffer[readIndex].ay, 2); dataFile.print(",");
        dataFile.println(ringBuffer[readIndex].az, 2);
        // (Add gyro, lat, lng, time prints here to match your CSV headers)
        readIndex = (readIndex + 1) % BUFFER_SIZE;
      }
      
      dataFile.flush();

      // Capture post-crash data
      int postCrashFrames = 1000;
      int lastWrittenIndex = freezeIndex;

      while (postCrashFrames > 0) {
        if (headIndex != lastWrittenIndex) {
          lastWrittenIndex = (lastWrittenIndex + 1) % BUFFER_SIZE;
          dataFile.print(ringBuffer[lastWrittenIndex].timestamp_us); dataFile.print(",");
          dataFile.print(ringBuffer[lastWrittenIndex].ax, 2); dataFile.print(",");
          dataFile.print(ringBuffer[lastWrittenIndex].ay, 2); dataFile.print(",");
          dataFile.println(ringBuffer[lastWrittenIndex].az, 2);
          postCrashFrames--;
        } else {
          vTaskDelay(pdMS_TO_TICKS(1));
        }
      }
      
      dataFile.flush();
      dataFile.close();
      vTaskSuspend(NULL);
    }
  }
}

// --- SYSTEM INITIALIZATION ---
void setup() {
  Serial.begin(115200);
  gpsSerial.begin(GPS_BAUD, SERIAL_8N1, RXD2, TXD2);
  Wire.begin();
  Wire.setClock(400000); 
  analogReadResolution(12);

  // Initialize Sensors
  if (imu.beginI2C(0x68) != BMI2_OK) {
    Serial.println("BMI270 NOT DETECTED");
    while (1);
  }
  if (!rtc.begin()){
    Serial.println("Cannot find RTC");
    while (1);
  }
  if(rtc.lostPower()) {
    rtc.adjust(DateTime(F(__DATE__), F(__TIME__)));
  }
  
  // Initialize SD Card
  if (!SD.begin(SD_CS_PIN)) {
    Serial.println("SD Card Mount Failed");
    while (1);
  }

  // Create IPC Queue
  crashQueue = xQueueCreate(1, sizeof(int));
  if(crashQueue == NULL){
    Serial.println("ERROR: Queue allocation failed.");
    while(1);
  }

  // Pin Tasks to Cores
  xTaskCreatePinnedToCore(core0_SensorTask, "SensorTask", 4096, NULL, 2, &SensorTaskHandle, 0);
  xTaskCreatePinnedToCore(core1_SDTask, "SDTask", 8192, NULL, 1, &SDTaskHandle, 1);
}

void loop() {
  vTaskDelete(NULL); // Kill default loop to free Core 1
}

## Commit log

2026-07-23 journaled researched and PCB started
    [Crashsense.kicad_pcb, Crashsense.kicad_sch]
2026-07-23 pushing KICAD flies PCB schematic
    [Crashsense.kicad_sch]
2026-07-24 progressed on PCB and journalled for today
    [Crashsense.kicad_sch]
2026-07-24 pcb updates?
2026-07-25 finished PCB and journalled
    [Crashsense.kicad_pcb, Crashsense.kicad_sch]
2026-07-26 Finished PCB componen placement and journalling
    [Crashsense.kicad_pcb, Crashsense.kicad_sch]
2026-07-27 jopurnal for today
    [Crashsense.kicad_pcb]
2026-07-28 updated things
    [Crashsense.kicad_sch]
2026-07-28 PCb rerouting started and journalled for today
    [Crashsense.kicad_pcb]
2026-07-29 PCb finished and journalled for today
    [Crashsense.kicad_pcb]
2026-07-30 rendered the PCB and exported manufacturing files
    [bom.csv, designators.csv, positions.csv]
2026-08-02 journaled and exported nd organised files
    [Crahsense outter shel part-2 v4.f3d, Crahsense outter shel part-2 v4.step, Crashsense Mark-1 Enclosure Part-1 v24.f3d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]
